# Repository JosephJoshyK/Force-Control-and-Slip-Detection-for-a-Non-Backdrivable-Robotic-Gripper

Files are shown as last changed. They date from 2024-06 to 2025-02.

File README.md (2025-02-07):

# Force Control and Slip Detection for a Non-Backdrivable Robotic Gripper

## What the Project Does

This project focuses on the development and implementation of a force control and slip detection system for a non-backdrivable robotic gripper. The system aims to enhance the gripper's ability to handle objects with varying levels of grip strength, ensuring that it can securely hold items without causing damage. The project includes the following components:
- Force control algorithms to adjust the gripping force based on real-time feedback.
- Slip detection mechanisms to identify when an object is slipping and adjust the grip accordingly.
- Experimental validation and testing of the system using various objects and scenarios.

### Force Control Demonstration

<p align="center">
  Uncontrolled Grasp
  Force Controlled Grasp
</p>
<p align="center">
  <i>Uncontrolled Grasp</i> &nbsp;&nbsp;&nbsp;&nbsp;&nbsp;&nbsp;&nbsp;&nbsp; <i>Force Controlled Grasp</i>
</p>

### Slip Detection Demonstration

<p align="center">
  Bottle Slip Detection
</p>
<p align="center">
  <i>Bottle Slip Detection</i>
</p>

## Why the Project is Useful

This project is particularly useful for applications in industrial automation, where precise handling of delicate or variable objects is critical. The ability to control grip force and detect slip in real-time can:
- Reduce damage to sensitive components.
- Improve the efficiency and reliability of automated handling systems.
- Enable the gripper to adapt to a wide range of objects, increasing its versatility.

## How Users Can Get Started with the Project

To get started with this project, follow these steps:

1. **Clone the repository:**
    ```bash
    git clone [https://github.com/JosephJoshyK/Force-Control-and-Slip-Detection-for-a-Non-Backdrivable-Robotic-Gripper.git
    cd Force-Control-and-Slip-Detection-for-a-Non-Backdrivable-Robotic-Gripper
    ```

3. **Setup the Hardware:** Follow the instructions in the `FSR Setup`, `Gripper Setup`, and `Complete Setup` folders to set up the robotic gripper and connect the FSR sensors.

    - **FSR Setup:**
      - Navigate to the `FSR Setup` folder.
      - Follow the detailed setup guide to correctly position and connect the FSR sensors.

    - **Gripper Setup:**
      - Navigate to the `Gripper Setup` folder.
      - Follow the step-by-step instructions to configure the robotic gripper.

    - **Complete Setup:**
      - Navigate to the `Complete Setup` folder.
      - Follow the comprehensive guide to ensure all components are correctly integrated and configured.

4. **Launch the fsr_main codes:**
    ```bash
    roslaunch fsr_main smart_grip.launch
    ```

For more detailed instructions, refer to the `README.md` in each folder.

## Where Users Can Get Help with Your Project

If you encounter any issues or have questions about the project, you can:
- **Open an Issue:** Create a new issue in the GitHub repository for any bugs or feature requests.
- **Discussions:** Participate in discussions on the GitHub Discussions page for this project.
- **Documentation:** Refer to the `README.md` folder for detailed documentation on the system architecture, setup, and usage.

## Acknowledgements

This project is developed to enhance the performance of a non-backdrivable robotic gripper by implementing advanced force control and slip detection mechanisms. Special thanks to the developers of the ROS and Robotiq 3F Gripper control package for their invaluable tools and support.

## Who Maintains and Contributes to the Project

This project is maintained by Joseph Joshy. Contributions are welcome! If you'd like to contribute, please fork the repository and create a pull request with your changes. Ensure your code adheres to the project's coding standards and includes relevant tests.

---

Feel free to reach out if you have any questions or need further assistance. Thank you for your interest in our project!

## Citation

If you find this useful, please [cite](https://ieeexplore.ieee.org/abstract/document/10730714):

```
J. Joshy, B. Sebastian and A. Thondiyath,
"Force Control and Slip Detection for A Non-Backdrivable Robotic Gripper,"
2024 IEEE International Conference on Artificial Intelligence in Engineering and Technology (IICAIET), Kota Kinabalu, Malaysia, 2024,
pp. 171-176,
doi: 10.1109/IICAIET62352.2024.10730714. 

}
```

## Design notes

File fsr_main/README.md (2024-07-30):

# FSR Main Package

The FSR Main package integrates force-sensitive resistors (FSRs) with a UR5 robot arm and a Robotiq 3-Finger Gripper using ROS (Robot Operating System). This README provides an overview of the package structure, functionality, and instructions for running the nodes.

## Package Contents

1. **Custom Message Definition**:
   - `FSRValues.msg`: Defines a custom ROS message type for publishing FSR values and corresponding force readings.

2. **ROS Nodes**:
   - `frc_slp_ctrl.py`: Controls the Robotiq 3-Finger Gripper based on FSR readings. Implements force control and slip detection logic.
   - `fsr_read.py`: Reads FSR data from a serial port, maps it to force values using polynomial functions derived from calibration data, and publishes the results.

3. **Launch File**:
   - `smart_grip.launch`: Launches all necessary nodes (`fsr_read.py`, `frc_slp_ctrl.py`, and `Robotiq3FGripperTcpNode.py`) to operate the system.

4. **Configuration Files**:
   - `CMakeLists.txt`: CMake build system configuration.
   - `package.xml`: Package manifest containing package dependencies and information.

5. **Source Files**:
   - `sheets`: Directory containing Excel sheets (`FSR_2.xlsx`, `FSR_3.xlsx`, `FSR_4.xlsx`) used for FSR calibration.

## Dependencies

- ROS (tested with Kinetic and Melodic)
- `robotiq_3f_gripper_articulated_msgs` package
- Python 3.x
- `numpy`, `pandas`, `matplotlib` Python libraries

## Running the Package

### Method 1: Individual Node Execution

1. Start ROS master node:
   ```bash
   roscore
   ```

2. Read FSR Data and Publish Force Values: Run `fsr_read.py` to read FSR data from a serial port and publish force values.

   ```bash
   rosrun fsr_main fsr_read.py
   ```

3. Control the Robotiq 3-Finger Gripper: Run `Robotiq3FGripperTcpNode.py` to control the Robotiq 3-Finger Gripper. Adjust the IP address as per your setup.

   ```bash
   rosrun robotiq_3f_gripper_control Robotiq3FGripperTcpNode.py 192.168.1.11
   ```

4. Implement Force Control and Slip Detection Logic: Run `frc_slp_ctrl.py` to implement force control and slip detection logic based on FSR readings.

   ```bash
   rosrun fsr_main frc_slp_ctrl.py
   ```

### Method 2:  Launch File Execution

1. Start ROS master node:
   ```bash
   roscore
   ```

2. Launch All Nodes Using `smart_grip.launch`: Launch the `smart_grip.launch` file to execute `fsr_read.py`, `Robotiq3FGripperTcpNode.py`, and `frc_slp_ctrl.py` simultaneously. This streamlines the setup process.

   ```bash
   roslaunch fsr_main smart_grip.launch
   ```
This launch file handles the coordinated execution of all nodes required for the FSR integration with the UR5 robot arm and Robotiq 3-Finger Gripper.

## Code Description

### FSR Data Reading and Publishing (`fsr_read.py`)

This script reads data from the FSR sensors and publishes it as a ROS message of type `FSRValues`.

#### Initialization:

- Initializes the ROS node and publisher.
- Reads calibration data from the Excel sheets to fit polynomial functions for force mapping.

#### Main Loop:

- Continuously reads FSR sensor data from the serial port.
- Maps the FSR values to force values using the polynomial functions.
- Publishes the FSR and force values as a ROS message.

### Force Control and Slip Detection (`frc_slp_ctrl.py`)

This script implements the force control and slip detection logic for the robotic gripper. It subscribes to the FSR values published by the `fsr_read.py` script and controls the gripper's position and force based on the real-time feedback.

#### Initialization:

- Initializes the ROS node and publishers/subscribers.
- Sets the desired force thresholds.
- Initializes various arrays and variables to track force and FSR values.

#### Main Loop:

- Continuously reads FSR values.
- Adjusts the gripper position and force based on the real-time feedback.
- Detects slip conditions and takes corrective actions.

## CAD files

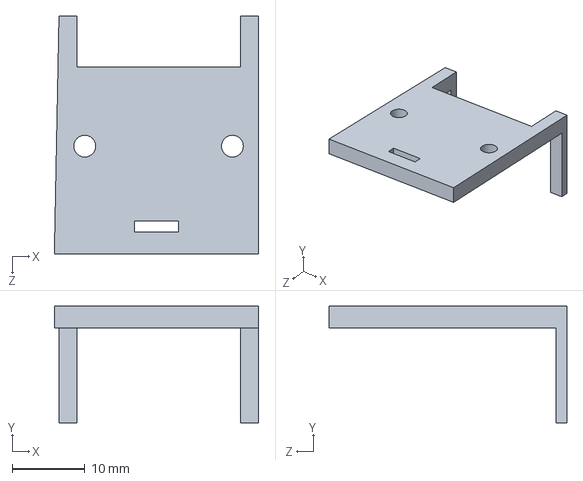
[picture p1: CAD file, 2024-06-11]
Complete Setup/CAD Files Fingertip/Casing hook/Casing Hook.SLDPRT
28.0 x 16.0 x 32.6 mm

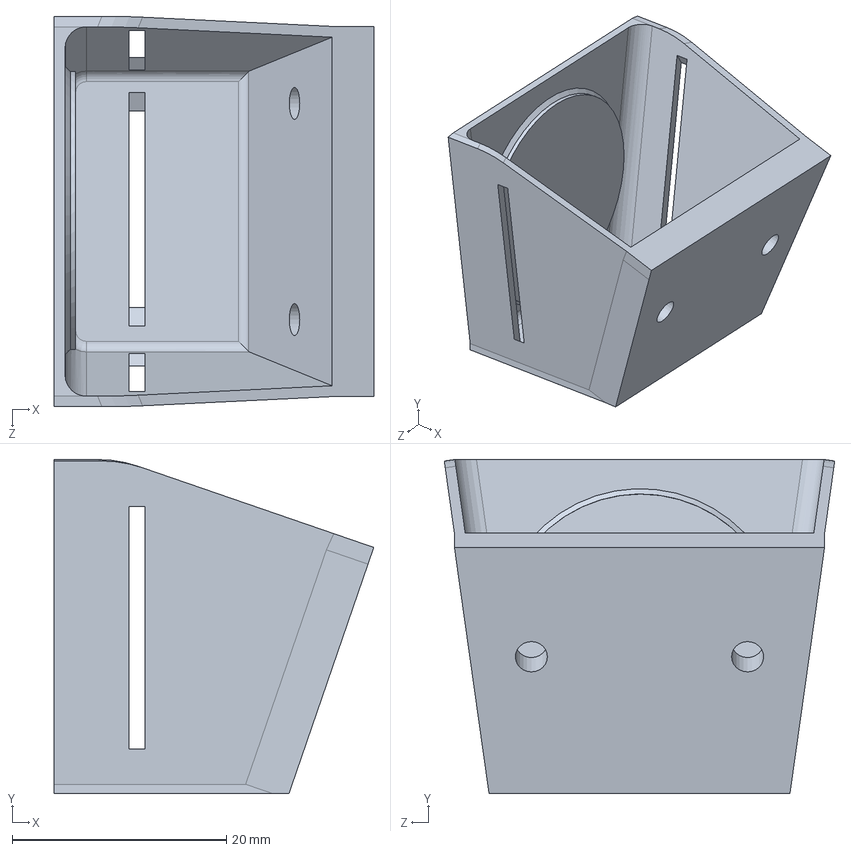
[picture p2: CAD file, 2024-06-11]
Complete Setup/CAD Files Fingertip/Casing/Casing.SLDPRT
29.9 x 31.2 x 36.5 mm

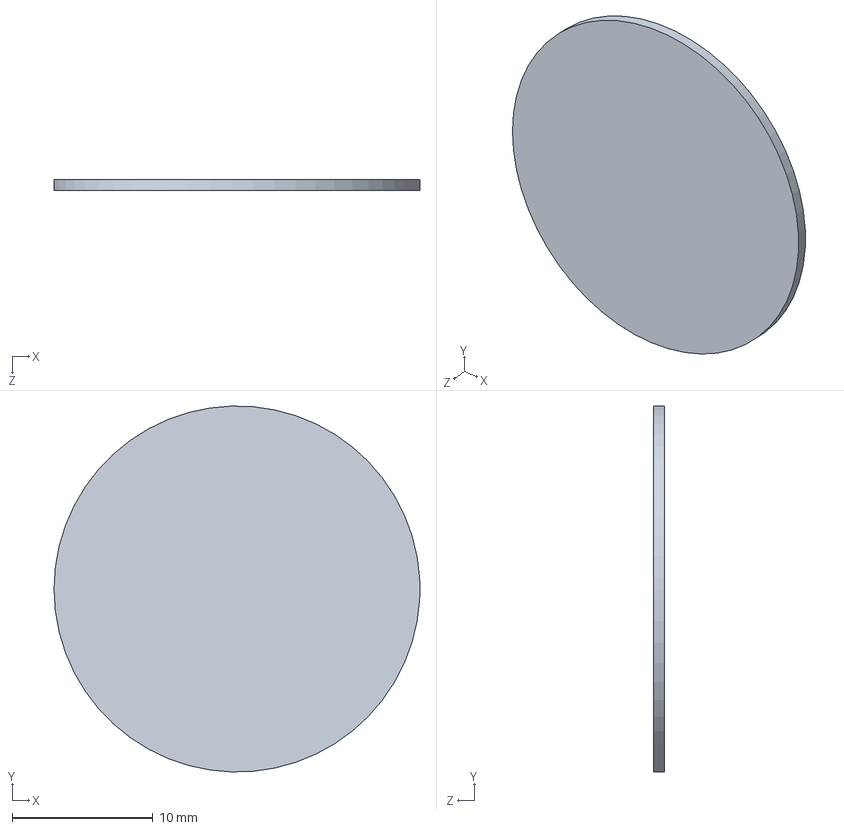
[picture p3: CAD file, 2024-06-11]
Complete Setup/CAD Files Fingertip/PLA solid disc/PLA solid disc.SLDPRT
26.0 x 26.0 x 0.8 mm

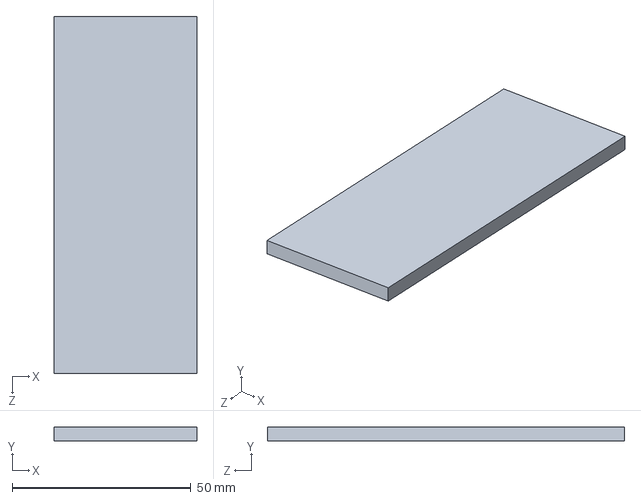
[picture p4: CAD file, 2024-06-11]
Complete Setup/CAD Files Fingertip/TPU flexible/TPU flexible.SLDPRT
40.0 x 4.00 x 100.0 mm

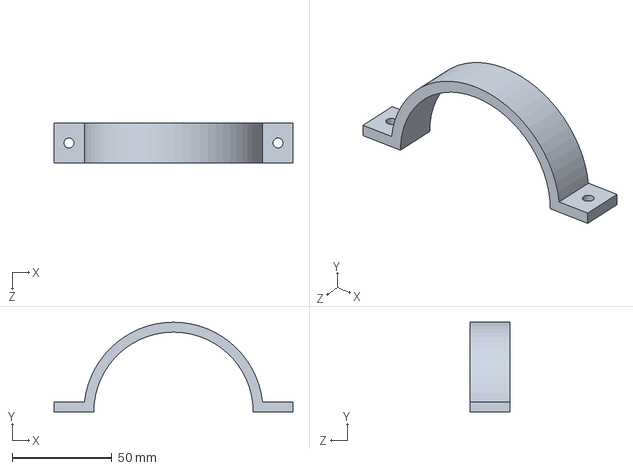
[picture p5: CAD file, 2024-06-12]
Complete Setup/CAD Files Mounting ring/Mounting ring Base/Mounting ring Base.SLDPRT
120.0 x 45.0 x 20.0 mm

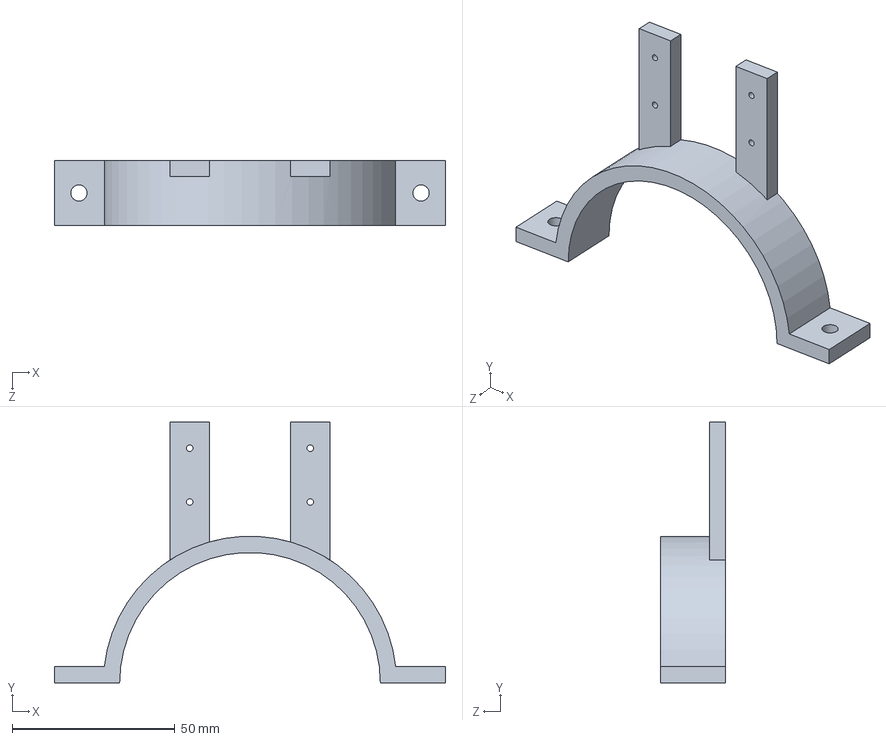
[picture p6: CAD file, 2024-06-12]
Complete Setup/CAD Files Mounting ring/Mounting ring Top/Mounting ring Top.SLDPRT
120.0 x 80.0 x 20.0 mm

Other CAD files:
Complete Setup/CAD Files Fingertip/Casing hook/Casing Hook.STL
Complete Setup/CAD Files Fingertip/PLA solid disc/PLA solid disc.STL
Complete Setup/CAD Files Fingertip/TPU flexible/TPU flexible.STL
Complete Setup/CAD Files Mounting ring/Mounting ring Base/Mounting ring Base.STL
Complete Setup/CAD Files Mounting ring/Mounting ring Top/Mounting ring Top.STL

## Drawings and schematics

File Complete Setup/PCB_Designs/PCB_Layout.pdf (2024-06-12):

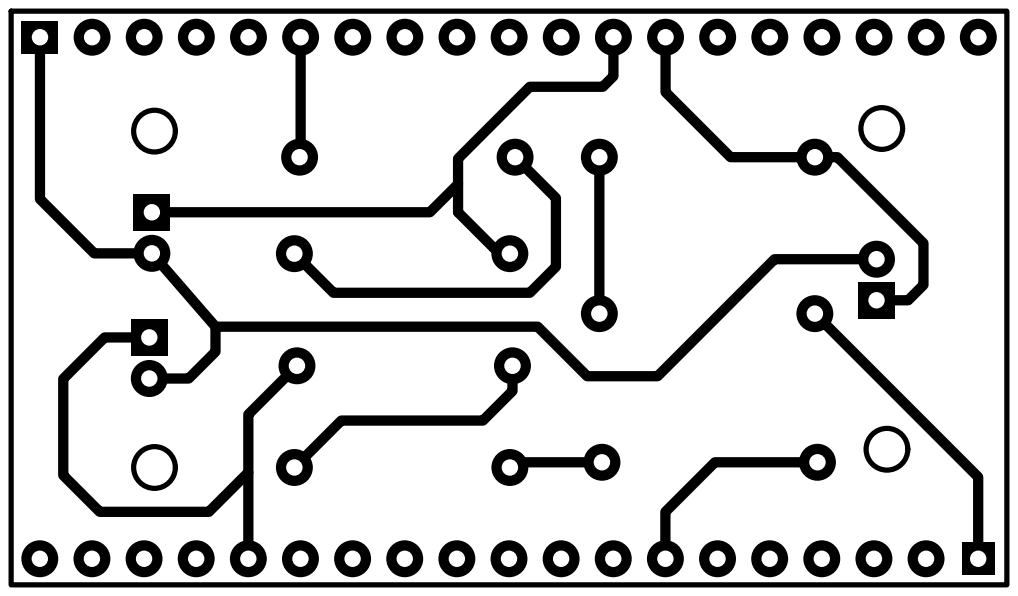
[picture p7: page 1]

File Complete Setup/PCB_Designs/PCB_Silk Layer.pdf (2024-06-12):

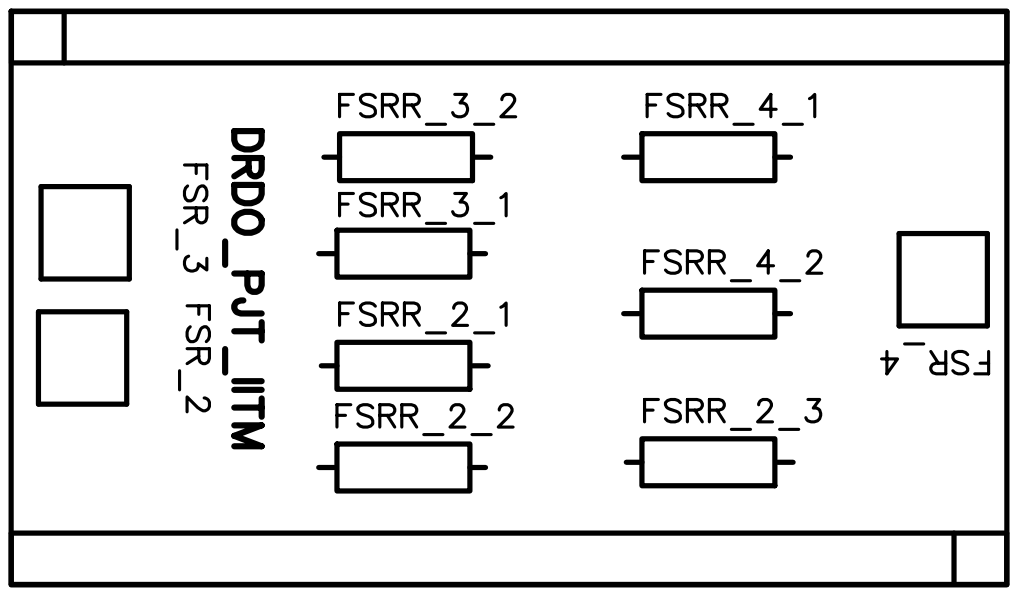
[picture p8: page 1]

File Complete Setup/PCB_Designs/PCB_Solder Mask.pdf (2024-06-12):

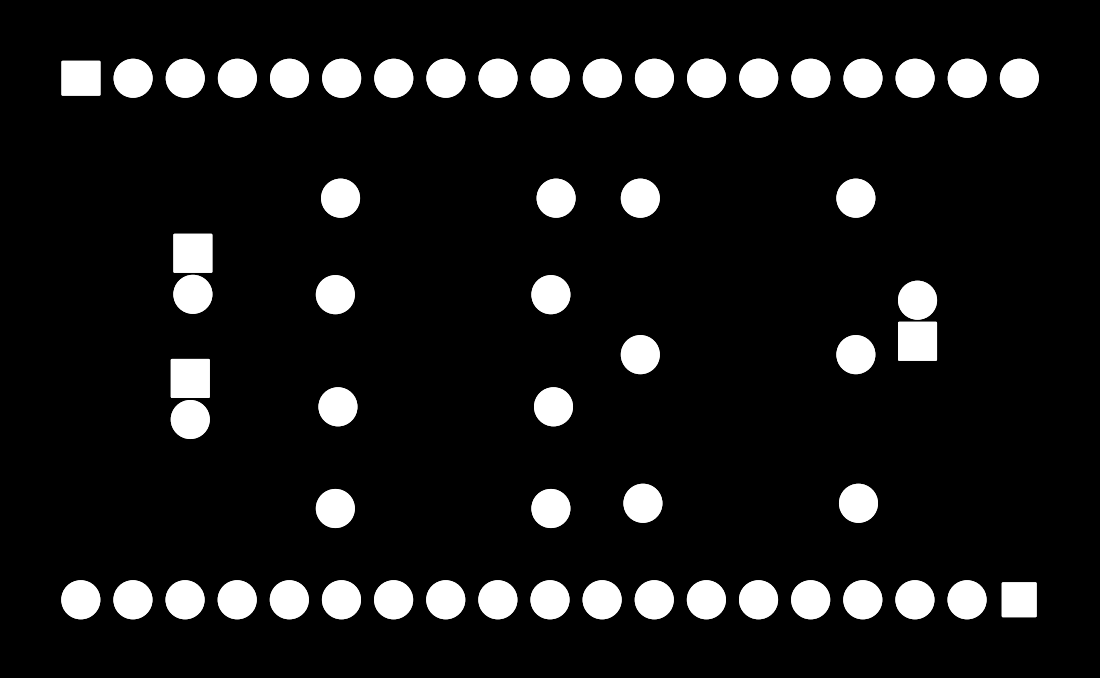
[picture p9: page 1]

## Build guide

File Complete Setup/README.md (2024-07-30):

# Complete Setup for Calibrated FSR Integration with Robotiq Gripper

## Overview
This project involves integrating calibrated Force Sensitive Resistors (FSRs) with a Robotiq gripper, facilitated by a custom-designed PCB and ESP32 microcontroller. The setup includes CAD files for various components and code for data collection and communication. The system is designed to be compact and efficient, with a specific focus on ease of attachment to the UR5 robot arm.

## Folder Structure
- **CAD Files Fingertip**: Contains CAD files for the finger pad used to attach the FSRs to the Robotiq gripper.
- **PCB_Designs**: Contains files for the designed PCB, which incorporates the voltage divider circuit for compact system integration.
- **CAD Files Mounting Ring**: Contains CAD files for the 3D-printed ring used to attach the PCB and ESP32 to the UR5 robot arm.
- **FSR_Data_Collector.ino**: Arduino code for collecting data from the FSRs and handling serial communication.

## Setup Instructions

### Step 1: Assemble the Finger Pad
1. Open the `CAD Files Fingertip` folder and locate the CAD files for the finger pad.
2. 3D print the finger pad.
3. Attach the calibrated FSRs to the finger pad as shown below:
   
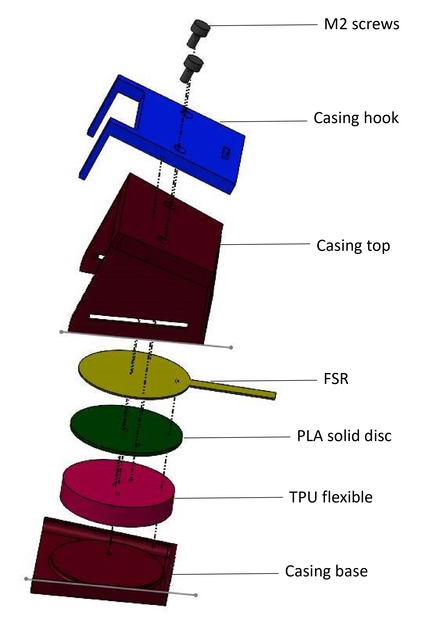
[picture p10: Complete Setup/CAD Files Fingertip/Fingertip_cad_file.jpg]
FSR Attachment Diagram


### Step 2: Connect FSRs to ESP32
1. Connect the three FSRs to ports 2, 32, and 33 of the ESP32.
2. Ensure secure connections to avoid any signal issues.

### Step 3: Upload Code to ESP32
1. Locate `FSR_Data_Collector.ino`.
2. Open `FSR_Data_Collector.ino` in the Arduino IDE.
3. Upload the code to the ESP32. This code handles data collection from the FSRs and serial communication.

### Step 4: Design and Attach the PCB
1. Open the `PCB_Designs` folder and locate the PCB design files.
2. Fabricate the PCB according to the design files.
3. Determine the appropriate resistance for the FSRs to ensure a good range of output for the required force readings. Experiment with a potentiometer to find the best match.
4. Solder the necessary components to the PCB, ensuring the voltage divider circuits are correctly assembled.
5. Attach the PCB to the ESP32, ensuring all connections are secure.

### Step 5: Mount the System on the UR5
1. Open the `CAD Files Mounting Ring` folder and locate the CAD files for the 3D-printed ring.
2. 3D print the ring.
3. Attach the PCB and ESP32 to the UR5 robot arm using the 3D-printed ring as shown below:
   
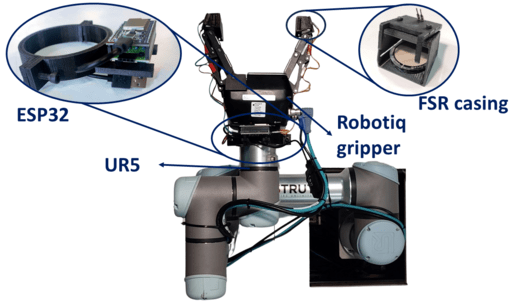
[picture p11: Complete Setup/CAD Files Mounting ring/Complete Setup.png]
Mounting PCB and ESP32 on UR5 Robot Arm
   

## Acknowledgements
- CAD models provided in `CAD Files Fingertip` and `CAD Files Mounting Ring`.
- PCB files are provided in `PCB_Designs`.
- Code developed for data collection and serial communication is provided in `FSR_Data_Collector.ino`.

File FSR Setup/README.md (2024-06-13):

# FSR Setup

## Overview

This folder contains the necessary files and instructions to set up the Force Sensitive Resistor (FSR) sensors for the robotic gripper. The setup includes uploading code to an ESP32 microcontroller, connecting the FSR to the ADC port, and calibrating the sensor using data collected from the ESP32 and ATI-Mini loadcell.

## Contents

- `serial_calib.ino`: Arduino code to upload to the ESP32 for reading FSR data.
- `ati_mini.cpp`: Code to interface with the ATI-Mini and collect data in parallel with the ESP32.
- `FSR_A.xlsx`,`FSR_B.xlsx`,`FSR_C.xlsx`: Excel file used to store and process the calibration data.

## Hardware Setup

1. **Connect the FSR to ESP32:**
    - Connect the FSR sensor to the 2nd ADC port on the ESP32.

2. **Upload the `serial_calib.ino` Code:**
    - Open the `serial_calib.ino` file in the Arduino IDE.
    - Select the correct board (ESP32) and port.
    - Upload the code to the ESP32.

## Calibration Process

1. **Ensure ESP32 serial communication**
    - Ensure the ESP32 is connected to your system via a serial connection.
    - The ESP32 will start reading data from the FSR and send it over serial communication.

2. **Run the `ati_mini.cpp` Code:**
    - Ensure the ATI mini loadcell is connected to your system via ethernet cable.
    - Compile and run the `ati_mini.cpp` file on your system.
    - This code will interface with the ATI-mini and sync the collected data in parallel with the ESP32 data.

4. **Collect Data:**
    - The data from both the ESP32 and the ATI-mini will be collected and stored in an Excel file.
    - Each sheet will have:
        - Column 5: Data from the ATI-mini which is force applied.
        - Column 9: Data from the ESP32.
    - Excel file for each force value is uploaded as different sheets in single Excel file as shown in `FSR_A.xlsx`,`FSR_B.xlsx`,`FSR_C.xlsx`.
    - Use the data in the `xlsx` file to derive the calibration equations for the FSR.
    - The final sheet in the Excel file will contain the averaged values and the curve.

## Calibration Equations

After processing the data, you will obtain calibration equations for the FSR. These equations will be used in the main application to convert raw sensor readings into meaningful force measurements.

Example calibration equation:
Force = a * {FSR Reading}^3 + b * {FSR Reading}^2 + c * {FSR Reading} + d 

## Example Calibration Equations

Example:
```markdown
## Calibration Equations

Based on the calibration data from FSR_A.xlsx, FSR_B.xlsx and FSR_C.xlsx for three different FSRs recpectively,
the following equations were derived for the FSR:

FA = 2.61e−9x^3 − 4.50e−6x^2 + 0.009x + 0.167
FB = 1.22e−9x^3 − 7.99e−7x^2 + 0.007x + 1.162
FC = 3.82e−9x^3 − 7.86e−6x^2 + 0.012x − 0.225
where x denotes the FSR Reading

These equations are used in the main application to convert the raw FSR readings into force measurements.

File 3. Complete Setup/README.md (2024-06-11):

# Complete Setup for Calibrated FSR Integration with Robotiq Gripper

## Overview
This project involves integrating calibrated Force Sensitive Resistors (FSRs) with a Robotiq gripper, facilitated by a custom-designed PCB and ESP32 microcontroller. The setup includes CAD files for various components and code for data collection and communication. The system is designed to be compact and efficient, with a specific focus on ease of attachment to the UR5 robot arm.

## Folder Structure
- **CAD_Files_Gripper**: Contains CAD files for the finger pad used to attach the FSRs to the Robotiq gripper.
- **PCB_Designs**: Contains files for the designed PCB, which incorporates the voltage divider circuit for compact system integration.
- **Mounting_Ring**: Contains CAD files for the 3D-printed ring used to attach the PCB and ESP32 to the UR5 robot arm.
- **FSR_Data_Collector.ino**: Arduino code for collecting data from the FSRs and handling serial communication.

## Setup Instructions

### Step 1: Assemble the Finger Pad
1. Open the `CAD_Files_Gripper` folder and locate the CAD files for the finger pad.
2. 3D print the finger pad.
3. Attach the calibrated FSRs to the finger pad as shown below:
   
   FSR Attachment Diagram

### Step 2: Connect FSRs to ESP32
1. Connect the three FSRs to ports 2, 3, and 4 of the ESP32.
2. Ensure secure connections to avoid any signal issues.

### Step 3: Upload Code to ESP32
1. Locate `FSR_Data_Collector.ino`.
2. Open `FSR_Data_Collector.ino` in the Arduino IDE.
3. Upload the code to the ESP32. This code handles data collection from the FSRs and serial communication.

### Step 4: Design and Attach the PCB
1. Open the `PCB_Designs` folder and locate the PCB design files.
2. Fabricate the PCB according to the design files.
3. Determine the appropriate resistance for the FSRs to ensure a good range of output for the required force readings. Experiment with a potentiometer to find the best match.
4. Solder the necessary components to the PCB, ensuring the voltage divider circuits are correctly assembled.
5. Attach the PCB to the ESP32, ensuring all connections are secure.

### Step 5: Mount the System on the UR5
1. Open the `Mounting_Ring` folder and locate the CAD files for the 3D-printed ring.
2. 3D print the ring.
3. Attach the PCB and ESP32 to the UR5 robot arm using the 3D-printed ring as shown below:
   
   Mounting PCB and ESP32 on UR5 Robot Arm

## Support
For any questions or issues, please contact josephkjoshy@gmail.com.

## Acknowledgements
- CAD models provided in `CAD_Files_Gripper` and `Mounting_Ring`.
- PCB files are provided in `PCB_Designs`.
- Code developed for data collection and serial communication is provided in `FSR_Data_Collector.ino`.

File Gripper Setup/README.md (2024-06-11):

# Instructions on controlling 3 finger gripper using ROS

The [ros-industrial repository](https://github.com/ros-industrial/robotiq) is unmaintained by robotiq and last distro support it has is of kinetic branch.

Another repository of [3 finger Robotiq gripper](https://github.com/TAMS-Group/robotiq) which is fork of ROS industrial is actively maintained by TAMS group from University of Hamburg and has the support of noetic distro.  

We want to control 3 finger gripper using Modbus TCP protocol  
Assuming you have cloned the repository mentioned above.

## Following instructions given on [3 finger robotiq gripper](http://wiki.ros.org/robotiq/Tutorials/Control%20of%20a%203-Finger%20Gripper%20using%20the%20Modbus%20TCP%20Protocol)

- The Gripper should be connected to a network, which has been properly configured (you can validate the communication with the Gripper using the [Robotiq User Interface](https://robotiq.com/support)). Make sure that external dependency of package "robotiq_modbus_tcp" is installed. The dependency is the python package pyModbus.

- Network configuration: Make sure that PC connected to gripper has static IP address different from default IP address of gripper which is 192.168.1.11

### Using ROS nodes to control gripper

- The Gripper is driven by the node "Robotiq3FGripperTcpNode.py" contained in the package "robotiq_3f_gripper_control". 
```
# change into the ur_ws workspace

cd ~/catkin_ws

# run the 3f gripper node, the IP address used here is the default IP address of gripper

rosrun robotiq_3f_gripper_control Robotiq3FGripperTcpNode.py 192.168.1.11
```
The driver listens for messages on "Robotiq3FGripperRobotOutput" using the "Robotiq3FGripper_robot_output" msg type. The messages are interpreted and commands are sent to the gripper accordingly

- In another terminal run a simple controller node 

```
rosrun robotiq_3f_gripper_control Robotiq3FGripperSimpleController.py
```
The simple controller node can be modified to send custom commands to the Gripper. 
```
'''here are some custom commands added to the Robotiq3FGripperSimpleController.py to operate each finger seperately'''

    if char == "fa_on":
        command.rICF = 1
        command.rPRA = 255

    if char == "fa_off":
        command.rPRA = 0
        command.rICF = 0        
       
    if char == "fb_on":
        command.rICF = 1
        command.rPRB = 255
    
    if char == "fb_off":
        command.rPRB = 0
        command.rICF = 0        
    
    if char == "fc_on":
        command.rICF = 1
        command.rPRC = 255

    if char == "fc_off":
        command.rPRC = 0
        command.rICF = 0        

```
- The status listener node can be run at another terminal.The driver publishes the status of the Gripper on "Robotiq3FGripperRobotInput" using the "Robotiq3FGripper_robot_input" msg type. 
```
rosrun robotiq_3f_gripper_control Robotiq3FGripperStatusListener.py

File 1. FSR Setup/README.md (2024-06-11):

# FSR Setup

## Overview

This folder contains the necessary files and instructions to set up the Force Sensitive Resistor (FSR) sensors for the robotic gripper. The setup includes uploading code to an ESP32 microcontroller, connecting the FSR to the ADC port, and calibrating the sensor using data collected from the ESP32 and ATI-Mini loadcell.

## Contents

- `serial_calib.ino`: Arduino code to upload to the ESP32 for reading FSR data.
- `ati_mini.cpp`: Code to interface with the ATI-Mini and collect data in parallel with the ESP32.
- `FSR_A.xlsx`,`FSR_B.xlsx`,`FSR_C.xlsx`: Excel file used to store and process the calibration data.
- `README.md`: Detailed instructions for the calibration process.

## Hardware Setup

1. **Connect the FSR to ESP32:**
    - Connect the FSR sensor to the 2nd ADC port on the ESP32.

2. **Upload the `serial_calib.ino` Code:**
    - Open the `serial_calib.ino` file in the Arduino IDE.
    - Select the correct board (ESP32) and port.
    - Upload the code to the ESP32.

## Calibration Process

1. **Ensure ESP32 serial communication**
    - Ensure the ESP32 is connected to your system via a serial connection.
    - The ESP32 will start reading data from the FSR and send it over serial communication.

2. **Run the `ati_mini.cpp` Code:**
    - Compile and run the `ati_mini.cpp` file on your system.
    - This code will interface with the ATI-mini and sync the collected data in parallel with the ESP32 data.

3. **Collect Data:**
    - The data from both the ESP32 and the ATI-mini will be collected and stored in an Excel file.
    - Each sheet will have:
        - Column 5: Data from the ATI-mini.
        - Column 9: Data from the ESP32.
    - Excel file for each force value is uploaded as different sheets in single Excel file as shown in `FSR_A.xlsx`,`FSR_B.xlsx`,`FSR_C.xlsx`.
    - Use the data in the `xlsx` file to derive the calibration equations for the FSR.
    - The final sheet in the Excel file will contain the averaged values and the curve.

## Calibration Equations

After processing the data, you will obtain calibration equations for the FSR. These equations will be used in the main application to convert raw sensor readings into meaningful force measurements.

Example calibration equation:
Force = a * {FSR Reading}^3 + b * {FSR Reading}^2 + c * {FSR Reading} + d 

## Example Calibration Equations

Example:
```markdown
## Calibration Equations

Based on the calibration data from sheet_a.xlsx, sheet_b.xlsx and sheet_c.xlsx for three different FSRs recpectively,
the following equations were derived for the FSR:

FA = 2.61e−9x^3 − 4.50e−6x^2 + 0.009x + 0.167
FB = 1.22e−9x^3 − 7.99e−7x^2 + 0.007x + 1.162
FC = 3.82e−9x^3 − 7.86e−6x^2 + 0.012x − 0.225
where x denotes the FSR Reading

These equations are used in the main application to convert the raw FSR readings into force measurements.

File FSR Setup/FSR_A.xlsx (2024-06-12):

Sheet: 0
No | time | Fx | Fy | Fz | Tx | Ty | Tz | fsr
1 | 15:27:39 | -0.11178 | -2.602057 | 0.206406 | -0.099505 | 0.011863 | 0.029943 | 0
2 | 15:27:39 | -0.106511 | -2.600689 | 0.225444 | -0.099407 | 0.011834 | 0.029913 | 0
3 | 15:27:39 | -0.112083 | -2.600055 | 0.203188 | -0.099407 | 0.011968 | 0.029897 | 0
4 | 15:27:39 | -0.108306 | -2.602057 | 0.212616 | -0.099459 | 0.01187 | 0.029865 | 0
5 | 15:27:39 | -0.106387 | -2.602978 | 0.222321 | -0.09942 | 0.011935 | 0.029972 | 0
6 | 15:27:39 | -0.109999 | -2.600982 | 0.209453 | -0.099498 | 0.011906 | 0.02992 | 0
7 | 15:27:39 | -0.111926 | -2.597616 | 0.212546 | -0.099481 | 0.01197 | 0.029921 | 0
8 | 15:27:39 | -0.109682 | -2.605138 | 0.215931 | -0.099566 | 0.011928 | 0.030024 | 0
9 | 15:27:39 | -0.111365 | -2.606295 | 0.209623 | -0.099617 | 0.011911 | 0.03005 | 0
10 | 15:27:39 | -0.110191 | -2.598636 | 0.216002 | -0.099398 | 0.011855 | 0.029941 | 0
11 | 15:27:39 | -0.104303 | -2.602072 | 0.215708 | -0.099545 | 0.011901 | 0.029948 | 0
12 | 15:27:39 | -0.109709 | -2.602931 | 0.215791 | -0.099597 | 0.011853 | 0.029968 | 0
13 | 15:27:39 | -0.108011 | -2.602094 | 0.212483 | -0.099548 | 0.012024 | 0.029953 | 0
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

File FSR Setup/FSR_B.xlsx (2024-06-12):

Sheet: 0
No | time | Fx | Fy | Fz | Tx | Ty | Tz | fsr
1 | 15:31:29 | 0.003708 | -0.004393 | 0.006334 | 2.1e-05 | 0.000157 | 3.4e-05 | 0
2 | 15:31:29 | 0.003544 | -0.002292 | 0.005915 | -1.1e-05 | 0.000237 | -9.2e-05 | 0
3 | 15:31:29 | 0.009114 | -0.003534 | 0.00625 | 7.3e-05 | 0.000204 | 1.4e-05 | 0
4 | 15:31:29 | 0.005349 | -0.003157 | 0.015598 | 2.9e-05 | 0.000149 | -7.2e-05 | 0
5 | 15:31:30 | -0.000125 | -0.00444 | 0.002957 | 1.8e-05 | 0.000281 | -3.9e-05 | 0
6 | 15:31:30 | 0.001676 | -0.006242 | 0.002978 | 1e-05 | 0.000116 | -0.000108 | 0
7 | 15:31:30 | -0.000353 | -0.004586 | -0.006107 | 0.00015 | 4.8e-05 | -5e-05 | 0
8 | 15:31:30 | 0.001797 | 0.0011 | 0.006332 | 5e-05 | 0.00017 | 6e-05 | 0
9 | 15:31:30 | 0.001567 | -0.005508 | 0.003599 | 0.00019 | 0.000113 | 5.6e-05 | 0
10 | 15:31:30 | -0.001918 | -0.005461 | 0.003032 | 1.1e-05 | 0.00029 | -1.4e-05 | 0
11 | 15:31:30 | -0.000512 | 4e-05 | 0.006402 | 0.000175 | 0.000103 | -7.7e-05 | 0
12 | 15:31:30 | 0.003367 | -0.009758 | -0.002902 | 0.000168 | 0.000153 | -2.6e-05 | 0
13 | 15:31:30 | 0.00331 | -0.000129 | 0.006403 | 0.000176 | 0.000236 | 1.1e-05 | 0
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

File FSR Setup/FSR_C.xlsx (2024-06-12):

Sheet: 0
No | time | Fx | Fy | Fz | Tx | Ty | Tz | fsr
1 | 15:27:39 | -0.11178 | -2.602057 | 0.206406 | -0.099505 | 0.011863 | 0.029943 | 0
2 | 15:27:39 | -0.106511 | -2.600689 | 0.225444 | -0.099407 | 0.011834 | 0.029913 | 0
3 | 15:27:39 | -0.112083 | -2.600055 | 0.203188 | -0.099407 | 0.011968 | 0.029897 | 0
4 | 15:27:39 | -0.108306 | -2.602057 | 0.212616 | -0.099459 | 0.01187 | 0.029865 | 0
5 | 15:27:39 | -0.106387 | -2.602978 | 0.222321 | -0.09942 | 0.011935 | 0.029972 | 0
6 | 15:27:39 | -0.109999 | -2.600982 | 0.209453 | -0.099498 | 0.011906 | 0.02992 | 0
7 | 15:27:39 | -0.111926 | -2.597616 | 0.212546 | -0.099481 | 0.01197 | 0.029921 | 0
8 | 15:27:39 | -0.109682 | -2.605138 | 0.215931 | -0.099566 | 0.011928 | 0.030024 | 0
9 | 15:27:39 | -0.111365 | -2.606295 | 0.209623 | -0.099617 | 0.011911 | 0.03005 | 0
10 | 15:27:39 | -0.110191 | -2.598636 | 0.216002 | -0.099398 | 0.011855 | 0.029941 | 0
11 | 15:27:39 | -0.104303 | -2.602072 | 0.215708 | -0.099545 | 0.011901 | 0.029948 | 0
12 | 15:27:39 | -0.109709 | -2.602931 | 0.215791 | -0.099597 | 0.011853 | 0.029968 | 0
13 | 15:27:39 | -0.108011 | -2.602094 | 0.212483 | -0.099548 | 0.012024 | 0.029953 | 0
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

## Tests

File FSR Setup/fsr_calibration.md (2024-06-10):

# FSR Setup

## Overview

This folder contains the necessary files and instructions to set up the Force Sensitive Resistor (FSR) sensors for the robotic gripper. The setup includes uploading code to an ESP32 microcontroller, connecting the FSR to the ADC port, and calibrating the sensor using data collected from the ESP32 and ATI-Mini loadcell.

## Contents

- `serial_calib.ino`: Arduino code to upload to the ESP32 for reading FSR data.
- `galil_bridge.cpp`: Code to interface with the ATI-Mini and collect data in parallel with the ESP32.
- `calibration_data.xlsx`: Excel file used to store and process the calibration data.
- `fsr_calibration.md`: Detailed instructions for the calibration process.

## Hardware Setup

1. **Connect the FSR to ESP32:**
    - Connect the FSR sensor to the 7th ADC port on the ESP32.

2. **Upload the `serial_calib.ino` Code:**
    - Open the `serial_calib.ino` file in the Arduino IDE.
    - Select the correct board (ESP32) and port.
    - Upload the code to the ESP32.

## Calibration Process

1. **Ensure ESP32 serial communication**
    - Ensure the ESP32 is connected to your system via a serial connection.
    - The ESP32 will start reading data from the FSR and send it over serial communication.

2. **Run the `galil_bridge.cpp` Code:**
    - Compile and run the `galil_bridge.cpp` file on your system.
    - This code will interface with the ATI-mini and sync the collected data in parallel with the ESP32 data.

3. **Collect Data:**
    - The data from both the ESP32 and the ATI-mini will be collected and stored in an Excel file (`calibration_data.xlsx`).
    - The Excel file will have multiple sheets:
        - Column 5: Data from the ATI-mini.
        - Column 9: Data from the ESP32.
    - Use the data in the `calibration_data.xlsx` file to derive the calibration equations for the FSR.
    - The final sheet in the Excel file will contain the averaged values and the curve.

## Calibration Equations

After processing the data, you will obtain calibration equations for the FSR. These equations will be used in the main application to convert raw sensor readings into meaningful force measurements.

Example calibration equation:
Force = a * {FSR Reading}^3 + b * {FSR Reading}^2 + c * {FSR Reading} + d 

## Example Calibration Equations

Example:
```markdown
## Calibration Equations

Based on the calibration data from sheet_a.xlsx, sheet_b.xlsx and sheet_c.xlsx for three different FSRs recpectively,
the following equations were derived for the FSR:

FA = 2.61e−9x^3 − 4.50e−6x^2 + 0.009x + 0.167
FB = 1.22e−9x^3 − 7.99e−7x^2 + 0.007x + 1.162
FC = 3.82e−9x^3 − 7.86e−6x^2 + 0.012x − 0.225
where x denotes the FSR Reading

These equations are used in the main application to convert the raw FSR readings into force measurements.

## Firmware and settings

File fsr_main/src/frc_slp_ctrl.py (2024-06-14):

#!/usr/bin/env python3

from __future__ import print_function
import rospy
from robotiq_3f_gripper_articulated_msgs.msg import Robotiq3FGripperRobotOutput
# from robotiq_3f_gripper_articulated_msgs.msg import Robotiq3FGripperRobotInput
import numpy as np
from fsr_main.msg import FSRValues
from decimal import Decimal, ROUND_HALF_UP
from datetime import datetime
import time

# Initialize ROS node
rospy.init_node('gripper_control_logic', anonymous=True)

# Set the desired force threshold
FORCE_THRESHOLD_MIN = 15
FORCE_THRESHOLD_MAX = 48
init_time = 1

# Publisher for Robotiq3FGripperRobotOutput messages
pub = rospy.Publisher("Robotiq3FGripperRobotOutput", Robotiq3FGripperRobotOutput, queue_size=10)

# Initial command setup
command = Robotiq3FGripperRobotOutput()
command.rACT = 1
command.rGTO = 1
command.rMOD = 0
command.rPRA = 0
command.rFRA = 50
command.rSPA = 255
pub.publish(command)

# Initialize arrays and variables
force_v = []
force_w = []
force_x = []

fsr_v = 0
fsr_w = 0
fsr_x = 0
force_v = 0
force_w = 0
force_x = 0

v = []
w = []
x = []

value_stack_v = []
value_stack_w = []
value_stack_x = []

# Initialize lists to store incoming values
fsr_v_val = []
fsr_w_val = []
fsr_x_val = []

decrease_detected_v = False
decrease_detected_w = False
decrease_detected_x = False

previous_value_v = 0
previous_value_w = 0
previous_value_x = 0

# Define global variables to track force thresholds
force_v_reached_threshold = False
force_w_reached_threshold = False
force_x_reached_threshold = False

def detect_slip(values):
    """
    Detect slip based on the values provided.

    Args:
        values (list): List of values to check for slip.

    Returns:
        bool: True if slip is detected, False otherwise.
    """
    min_value = min(values)
    negative_values = [value for value in values if value < 0 and value != min_value]

    if len(negative_values) >= 1:
        average_negative = sum(negative_values) / len(negative_values)
    else:
        average_negative = -30

    slip_detected = min_value < 10 * average_negative
    return slip_detected

def fsr_values_callback(msg):
    """
    Callback function to process FSR values from the subscribed topic.

    Args:
        msg (FSRValues): The message containing FSR values.
    """
    global fsr_v, fsr_w, force_v, fsr_x, force_w, force_x
    fsr_v = msg.fsr_v
    fsr_w = msg.fsr_w
    fsr_x = msg.fsr_x
    force_v = msg.force_v
    force_w = msg.force_w
    force_x = msg.force_x

def update_value_stack(stack, value):
    """
    Update the stack of values by adding the new value and removing the oldest value if the stack size exceeds 5.

    Args:
        stack (list): The stack to update.
        value (int): The new value to add.
    """
    stack.append(value)

    if len(stack) > 5:
        stack.pop(0)

def p_control(force_value, force_threshold_min, kp=0.5):
    """
    Proportional control function to calculate control output.

    Args:
        force_value (float): The current force value.
        force_threshold_min (float): The minimum force threshold.
        kp (float): The proportional gain.

    Returns:
        int: The control output.
    """
    error = force_threshold_min - force_value
    control_output = kp * error
    control_output = int(Decimal(control_output).quantize(Decimal('1'), rounding=ROUND_HALF_UP))

    # Ensure the control output is within the desired range (1 to 3)
    add_val = max(1, min(3, control_output))
    
    return add_val

def increment_position(command, add_val):
    """
    Increment the gripper position.

    Args:
        command (Robotiq3FGripperRobotOutput): The command to update.
        add_val (int): The value to add to the position.

    Returns:
        Robotiq3FGripperRobotOutput: The updated command.
    """
    command.rPRA += add_val
    return command

def decrement_position(command, sub_val):
    """
    Decrement the gripper position.

    Args:
        command (Robotiq3FGripperRobotOutput): The command to update.
        sub_val (int): The value to subtract from the position.

    Returns:
        Robotiq3FGripperRobotOutput: The updated command.
    """
    command.rPRA -= sub_val
    return command

def increment_force(command, add_val):
    """
    Increment the gripper force.

    Args:
        command (Robotiq3FGripperRobotOutput): The command to update.
        add_val (int): The value to add to the force.

    Returns:
        Robotiq3FGripperRobotOutput: The updated command.
    """
    command.rFRA += add_val
    return command

def decrement_force(command, sub_val):
    """
    Decrement the gripper force.

    Args:
        command (Robotiq3FGripperRobotOutput): The command to update.
        sub_val (int): The value to subtract from the force.

    Returns:
        Robotiq3FGripperRobotOutput: The updated command.
    """
    if command.rFRA > 50:
        command.rFRA -= sub_val
    
    return command

def main():
    """
    Main function to control the gripper based on FSR values and slip detection.
    """
    pub = rospy.Publisher("Robotiq3FGripperRobotOutput", Robotiq3FGripperRobotOutput, queue_size=10)
    fsr_sub = rospy.Subscriber("/fsr_values", FSRValues, fsr_values_callback)
    global force_v, force_w, force_x, fsr_v, fsr_w, fsr_x, command
    global init_time

    # Append values to the lists
    fsr_v_val.append(fsr_v)
    fsr_w_val.append(fsr_w)
    fsr_x_val.append(fsr_x)
    
    update_value_stack(value_stack_v, fsr_v)
    update_value_stack(value_stack_w, fsr_w)
    update_value_stack(value_stack_x, fsr_x)

    try:
        while not rospy.is_shutdown():      
            # Proportional control to increase the gripper position if the force is below the minimum threshold
            while (int(force_v < FORCE_THRESHOLD_MIN) + int(force_w < FORCE_THRESHOLD_MIN) + int(force_x < FORCE_THRESHOLD_MIN)) == 3 and command.rPRA < 253:
                add = p_control(force_v, FORCE_THRESHOLD_MIN)
                command = increment_position(command, add)
                pub.publish(command)
                rospy.sleep(0.1)

                # Append values to the lists
                fsr_v_val.append(fsr_v)
                fsr_w_val.append(fsr_w)
                fsr_x_val.append(fsr_x)

                update_value_stack(value_stack_v, fsr_v)
                update_value_stack(value_stack_w, fsr_w)
                update_value_stack(value_stack_x, fsr_x)

                init_time += 1

            # Decrease the gripper position and force if the force exceeds the maximum threshold
            while (int(force_v > FORCE_THRESHOLD_MAX) + int(force_w > FORCE_THRESHOLD_MAX) + int(force_x > FORCE_THRESHOLD_MAX)) > 0 and command.rPRA > 2 and command.rFRA > 24:
                command = decrement_position(command, 3)
                pub.publish(command)
                rospy.sleep(0.1)
                command = decrement_force(command, 25)            
                pub.publish(command)
                rospy.sleep(0.1)
                
                fsr_v_val.append(fsr_v)
                fsr_w_val.append(fsr_w)
                fsr_x_val.append(fsr_x)

                update_value_stack(value_stack_v, fsr_v)
                update_value_stack(value_stack_w, fsr_w)
                update_value_stack(value_stack_x, fsr_x)
            
            fsr_v_val.append(fsr_v)
            fsr_w_val.append(fsr_w)
            fsr_x_val.append(fsr_x)

            update_value_stack(value_stack_v, fsr_v)
            update_value_stack(value_stack_w, fsr_w)
            update_value_stack(value_stack_x, fsr_x)

            gradient_v = np.diff(value_stack_v)
            gradient_w = np.diff(value_stack_w)
            gradient_x = np.diff(value_stack_x)

            slip_detected_v = detect_slip(gradient_v)
            slip_detected_w = detect_slip(gradient_w)
            slip_detected_x = detect_slip(gradient_x)

            # If slip is detected, print the time
            if sum([slip_detected_v, slip_detected_w, slip_detected_x]) >= 2:
                current_time = datetime.now()
                formatted_time = current_time.strftime("%H:%M:%S")
                print('Slip detected! at:', formatted_time)

            init_time += 1   
            # Add a small delay if needed to control the data acquisition rate
            # time.sleep(0.1)

    except rospy.ROSInterruptException:
        pass
    finally:
        # Cleanup code
        print("Shutting down ROS node")
        command = Robotiq3FGripperRobotOutput()
        command.rACT = 0
        pub.publish(command)

if __name__ == "__main__":
    try:
        main()
    except KeyboardInterrupt:
        print("Keyboard interrupt detected. Exiting...")

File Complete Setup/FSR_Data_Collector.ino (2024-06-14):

#include <Arduino.h>

// Define the pins for the Force Sensitive Resistors (FSRs)
const int fsrPin2 = 2;  // ADC pin for the first FSR
const int fsrPin3 = 33; // ADC pin for the second FSR
const int fsrPin4 = 32; // ADC pin for the third FSR

// Define the baud rate for serial communication
const int baudRate = 921600;

void setup() {
  // Initialize serial communication at the defined baud rate
  Serial.begin(baudRate);
}

void loop() {
  // Read the analog values from the FSRs
  int fsrValue2 = analogRead(fsrPin2);
  int fsrValue3 = analogRead(fsrPin3);
  int fsrValue4 = analogRead(fsrPin4);

  // Construct a data packet with start and end markers
  Serial.print('<'); // Start marker
  Serial.print(fsrValue2);
  Serial.print(",");
  Serial.print(fsrValue3);
  Serial.print(",");
  Serial.print(fsrValue4);
  Serial.print('>'); // End marker

  // Add a delay to control the data transmission rate
  delay(102); // Adjust the delay as needed
}

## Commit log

2024-06-12 Rename Fingertip_cad_file (1).jpg to Fingertip_cad_file.jpg
2024-06-12 Rename Fingertip_cad_file (2).jpg to Fingertip_cad_file.jpg
